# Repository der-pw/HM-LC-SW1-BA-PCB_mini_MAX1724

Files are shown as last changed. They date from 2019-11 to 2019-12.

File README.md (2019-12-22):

# AskSin++ Batterieaktor mit MAX1724 Stepup

**HM-LC-SW1-BA-PCB_mini mit einer Ausgangsspannung von 3,3V, bspw. für Mini-Lichterketten.**




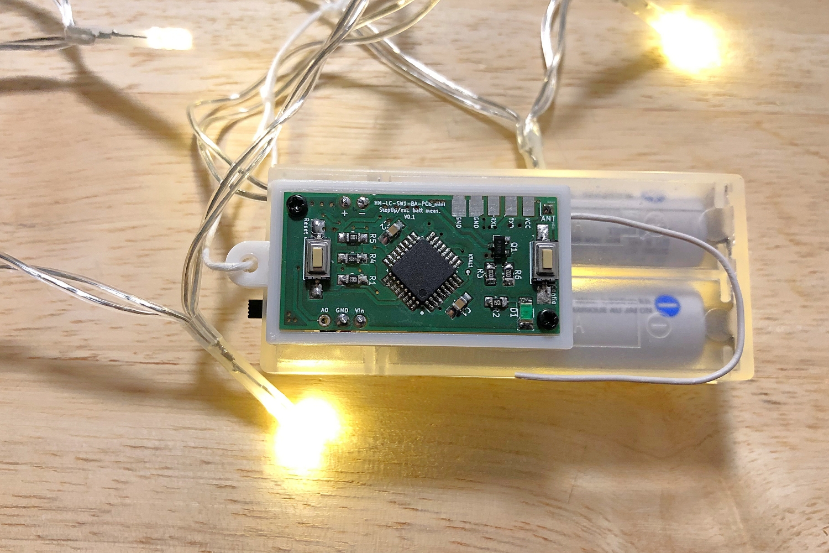
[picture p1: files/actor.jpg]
Aktor


* [Sketch](./Sketch/HM-LC-SW1-BA-PCB_extBatt.ino)
* [Gehäuse](./Case/)
* [Teileliste](./HM-LC-SW1-BA-PCB_mini_MAX1724-Parts.csv)

Der Ausgang wird über einen N-Channel MOSFET geschaltet und kann, je nach Versorgungsspannung, mit bis zu 150mA belastet werden.
Für kleine Mini-Lichterketten ist das ausreichend.
(Beispiel: eine Mini-Lichterkette aus den üblichen Grabbelschütten, mit 10 LEDs und 10Ohm Vorwiderstand benötigt ca 35mA).

**Batterie-Messung:**  
Desweiteren kann die Batteriespannung vor dem Stepup mittels Spannungsteiler gemessen werden. 
Ein angepasster Sketch liegt bei. Vielen Dank an Jérôme für die Unterstützung und das Aufzeigen, wie "einfach" doch die Batterieklasse ist. ;-)

Da in der CCU, bei diesem Aktor, die Batteriemeldung nur im Bereich von 5-15V auslöst, wird im Sketch unter ...
```
uint8_t lowbat = getList0().lowBatLimit() / 5; //factor 5 to get low bat
```
... die eingestellte Batterieschwelle durch 5 geteilt.
In der CCU müssen also die Spannungwerte mit "x5" angegeben werden.
Beispiel: Batteriemeldung bei 2,1V Versorgungsspannung. Heißt 2,1V x 5 = 10,5V. Es müssen demnach 10,5V in der CCU eingestellt werden.
Die Werte variieren je nach verwendetem Batterie.- Akkutyp und müssen "für sich selbst" gefunden werden.

## PCB

Das Platinendesign basiert auf dem [HMSensor](https://github.com/pa-pa/HMSensor/) Projekt.
Weitere Infos zur HMSensor gibt es auf [asksinpp.de](https://asksinpp.de/Projekte/psi/HMSensor/).

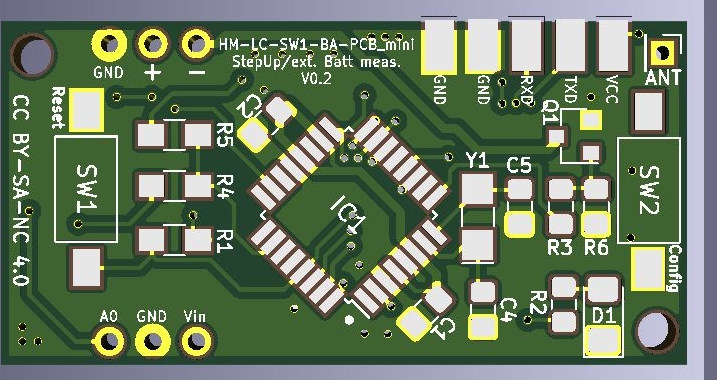
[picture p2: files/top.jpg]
PCB top

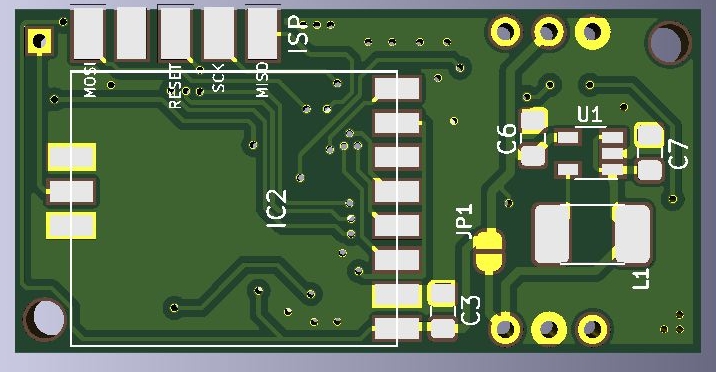
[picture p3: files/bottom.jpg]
PCB bottm


## FAQ

* `fatal error: ResetOnBoot.h: No such file or directory`  
  Es ist die aktuellste Version (ggf. master-Branch) der [AskSinPP](https://github.com/pa-pa/AskSinPP) Library zu verwenden

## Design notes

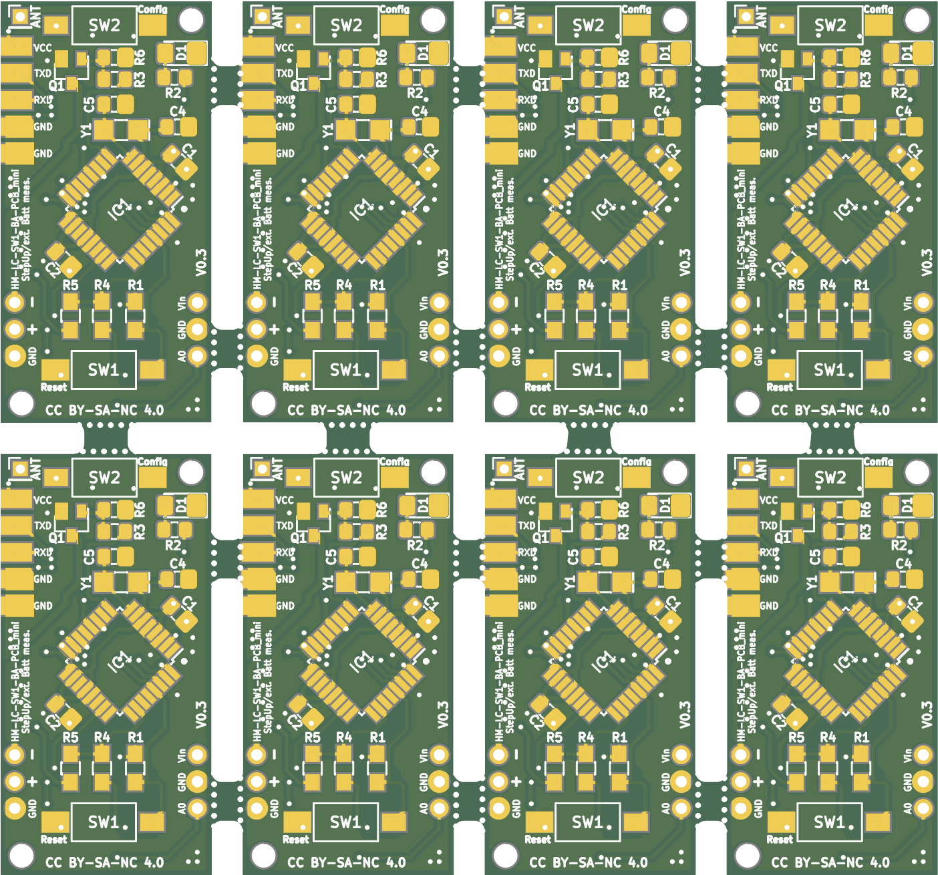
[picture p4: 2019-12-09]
Panel_2x4/unzipped/Untitled_Combined_Top.png

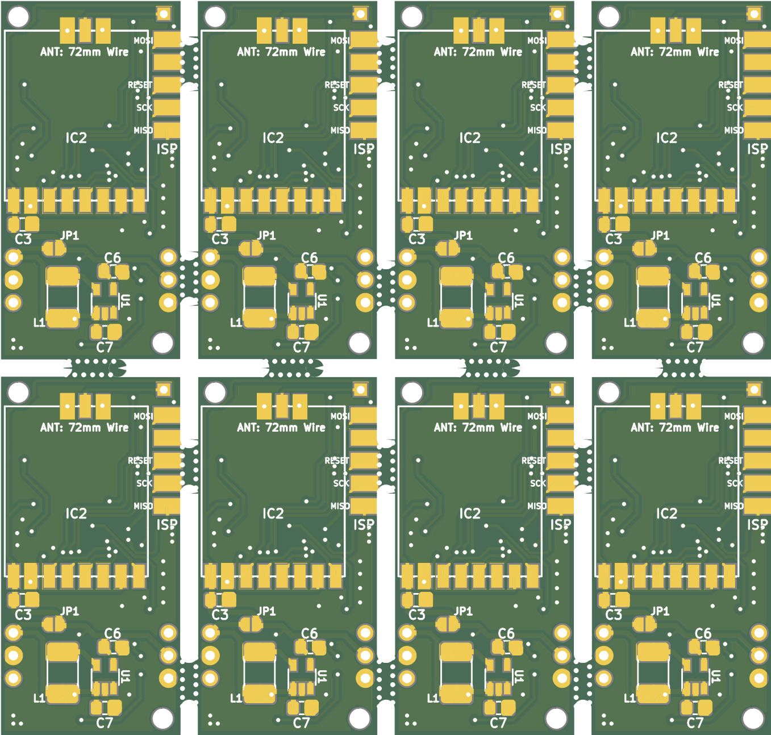
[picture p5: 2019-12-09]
Panel_2x4/Panel_2x4_Bottom.png

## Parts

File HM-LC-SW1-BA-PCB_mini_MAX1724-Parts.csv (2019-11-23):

Item | Qty | Reference(s) | Value | LibPart | Footprint | Datasheet
1 | 3 | C1, C2, C3 | 100n | Device:C | Capacitors_SMD:C_0805_HandSoldering
2 | 2 | C6, C7 | 10µ | Device:C | Capacitors_SMD:C_0805_HandSoldering
3 | 1 | D1 | LED Red | HM-LC-SW1-BA-PCB_mini_MAX1724-rescue:LED-HMSensor-StepUp-rescue-HM-LC-SW1-BA-PCB_mini2-rescue | LED_SMD:LED_1206_3216Metric_Pad1.42x1.75mm_HandSolder
4 | 1 | IC1 | ATMEGA328P-A | HM-LC-SW1-BA-PCB_mini_MAX1724-rescue:ATMEGA328P-A-HMSensor-StepUp-rescue-HM-LC-SW1-BA-PCB_mini2-rescue | Housings_QFP:TQFP-32_7x7mm_Pitch0.8mm
5 | 1 | IC2 | CC1101 | HM-LC-SW1-BA-PCB_mini_MAX1724-rescue:CC1101-HMSensor-StepUp-rescue-HM-LC-SW1-BA-PCB_mini2-rescue | Modules:CC1101_Module
6 | 1 | J1 | Conn_01x02_Female | Connector:Conn_01x02_Female | Connector_PinHeader_2.54mm:PinHeader_1x02_P2.54mm_Vertical | ~
7 | 1 | J2 | Conn_01x03_Female | Connector:Conn_01x03_Female | Connector_PinHeader_2.54mm:PinHeader_1x03_P2.54mm_Vertical | ~
8 | 1 | JP1 | Jumper_NO_Small | Device:Jumper_NO_Small | Jumper:SolderJumper-2_P1.3mm_Open_RoundedPad1.0x1.5mm
9 | 1 | L1 | 10µH | Device:L_Small | Inductor_SMD:L_1812_4532Metric_Pad1.30x3.40mm_HandSolder | https://de.aliexpress.com/item/32845690258.html
10 | 1 | P3 | ANT | HM-LC-SW1-BA-PCB_mini_MAX1724-rescue:CONN_01X01-HMSensor-StepUp-rescue-HM-LC-SW1-BA-PCB_mini2-rescue | Pin_Headers:Pin_Header_Straight_1x01_Pitch2.00mm
11 | 1 | P4 | ISP Bottom | HM-LC-SW1-BA-PCB_mini_MAX1724-rescue:CONN_01X05-HMSensor-StepUp-rescue-HM-LC-SW1-BA-PCB_mini2-rescue | Modules:Pin_Header_Straight_1x05_Pitch2.54mm_SMD_BySide
12 | 1 | P5 | ISP Top | HM-LC-SW1-BA-PCB_mini_MAX1724-rescue:CONN_01X05-HMSensor-StepUp-rescue-HM-LC-SW1-BA-PCB_mini2-rescue | Modules:Pin_Header_Straight_1x05_Pitch2.54mm_SMD_BySide
13 | 1 | Q1 | TSM2302 | Transistor_FET:IRLML2060 | Package_TO_SOT_SMD:SOT-23 | http://www.farnell.com/datasheets/1945672.pdf
14 | 1 | R1 | 10k | Device:R | Resistors_SMD:R_0805_HandSoldering
15 | 1 | R2 | 1k5 | Device:R | Resistor_SMD:R_0805_2012Metric_Pad1.15x1.40mm_HandSolder
16 | 1 | R3 | 100 | Device:R | Resistor_SMD:R_0805_2012Metric_Pad1.15x1.40mm_HandSolder
17 | 1 | R4 | 470k | Device:R | Resistors_SMD:R_0805_HandSoldering
18 | 1 | R5 | 100k | Device:R | Resistors_SMD:R_0805_HandSoldering
19 | 1 | R6 | 10k | Device:R | Resistor_SMD:R_0805_2012Metric_Pad1.15x1.40mm_HandSolder
20 | 1 | SW1 | Reset | HM-LC-SW1-BA-PCB_mini_MAX1724-rescue:SW_PUSH-HMSensor-StepUp-rescue-HM-LC-SW1-BA-PCB_mini2-rescue | Buttons_Switches_SMD:SW_SPST_FSMSM
21 | 1 | SW2 | Config | HM-LC-SW1-BA-PCB_mini_MAX1724-rescue:SW_PUSH-HMSensor-StepUp-rescue-HM-LC-SW1-BA-PCB_mini2-rescue | Buttons_Switches_SMD:SW_SPST_FSMSM
22 | 1 | U1 | MAX1724 | HM-LC-SW1-BA-PCB_mini_MAX1724-rescue:MAX1724-HM-LC-SW1-BA-PCB_mini2-rescue | Package_TO_SOT_SMD:TSOT-23-5 | https://de.aliexpress.com/item/32353066414.html

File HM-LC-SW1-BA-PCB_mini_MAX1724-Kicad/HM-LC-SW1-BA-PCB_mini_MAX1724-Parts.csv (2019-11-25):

Reference | Quantity | Value | Footprint | Datasheet
C1 C2 C3 | 3 | 100n | Capacitor_SMD:C_0805_2012Metric_Pad1.15x1.40mm_HandSolder
C4 C5 | 2 | 9p | Capacitor_SMD:C_0805_2012Metric_Pad1.15x1.40mm_HandSolder | ~
C6 C7 | 2 | 10µ | Capacitor_SMD:C_0805_2012Metric_Pad1.15x1.40mm_HandSolder
D1 | 1 | LED Red | LED_SMD:LED_1206_3216Metric_Pad1.42x1.75mm_HandSolder
IC1 | 1 | ATMEGA328P-A | Housings_QFP:TQFP-32_7x7mm_Pitch0.8mm
IC2 | 1 | CC1101 | Modules:CC1101_Module
J2 J1 | 2 | Conn_01x03_Female | Connector_PinHeader_2.54mm:PinHeader_1x03_P2.54mm_Vertical | ~
JP1 | 1 | Jumper_NO_Small | Jumper:SolderJumper-2_P1.3mm_Open_RoundedPad1.0x1.5mm
L1 | 1 | 10µH | Inductor_SMD:L_1812_4532Metric_Pad1.30x3.40mm_HandSolder | https://de.aliexpress.com/item/32845690258.html
P3 | 1 | ANT | Pin_Headers:Pin_Header_Straight_1x01_Pitch2.00mm
P4 | 1 | ISP Bottom | Modules:Pin_Header_Straight_1x05_Pitch2.54mm_SMD_BySide
P5 | 1 | ISP Top | Modules:Pin_Header_Straight_1x05_Pitch2.54mm_SMD_BySide
Q1 | 1 | TSM2302 | Package_TO_SOT_SMD:SOT-23 | http://www.farnell.com/datasheets/1945672.pdf
R1 | 1 | 10k | Resistors_SMD:R_0805_HandSoldering
R2 | 1 | 1k5 | Resistor_SMD:R_0805_2012Metric_Pad1.15x1.40mm_HandSolder
R3 | 1 | 100 | Resistor_SMD:R_0805_2012Metric_Pad1.15x1.40mm_HandSolder
R4 | 1 | 470k | Resistors_SMD:R_0805_HandSoldering
R5 | 1 | 100k | Resistors_SMD:R_0805_HandSoldering
R6 | 1 | 10k | Resistor_SMD:R_0805_2012Metric_Pad1.15x1.40mm_HandSolder
SW1 | 1 | Reset | Buttons_Switches_SMD:SW_SPST_FSMSM
SW2 | 1 | Config | Buttons_Switches_SMD:SW_SPST_FSMSM
U1 | 1 | MAX1724 | Package_TO_SOT_SMD:TSOT-23-5 | https://de.aliexpress.com/item/32353066414.html
Y1 | 1 | Crystal | Crystal:Crystal_SMD_MicroCrystal_CC7V-T1A-2Pin_3.2x1.5mm_HandSoldering | https://www.reichelt.de/uhrenquarz-keramikgeh-1-5x3-2x0-9mm-9pf-32-768-cc7v-9-p85050.html

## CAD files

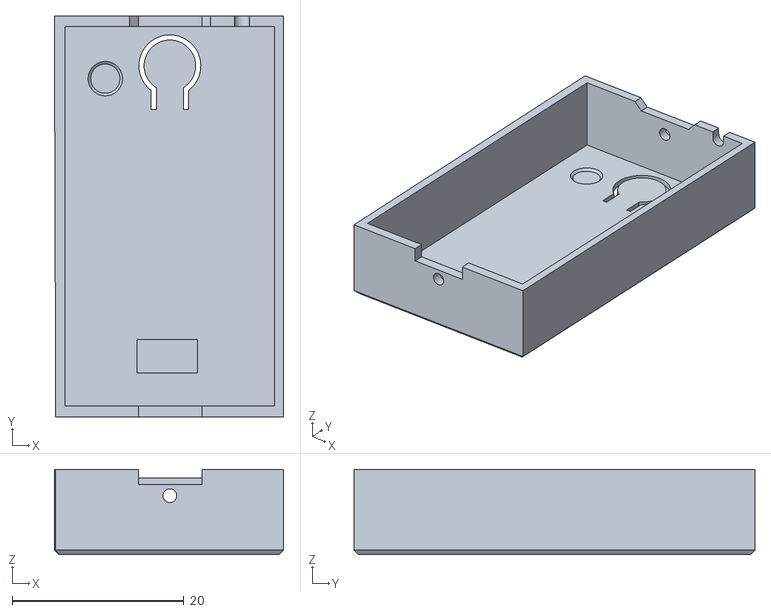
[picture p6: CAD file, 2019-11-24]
Case/Deckel.stl
26.7 x 46.7 x 9.90

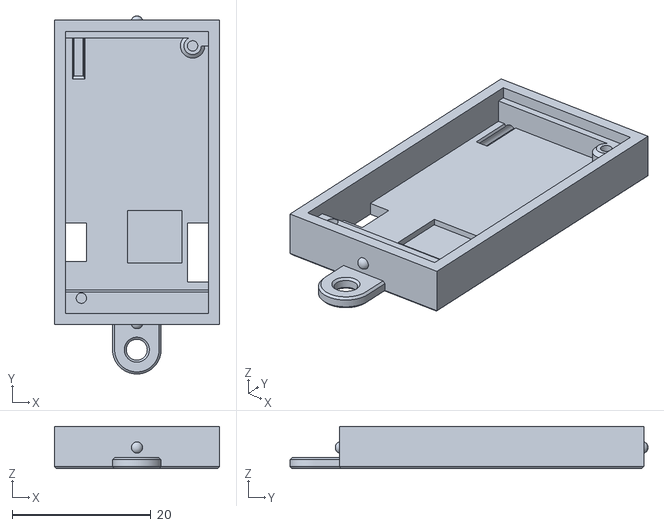
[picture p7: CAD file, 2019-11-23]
Case/Halter.stl
23.8 x 51.5 x 6.10

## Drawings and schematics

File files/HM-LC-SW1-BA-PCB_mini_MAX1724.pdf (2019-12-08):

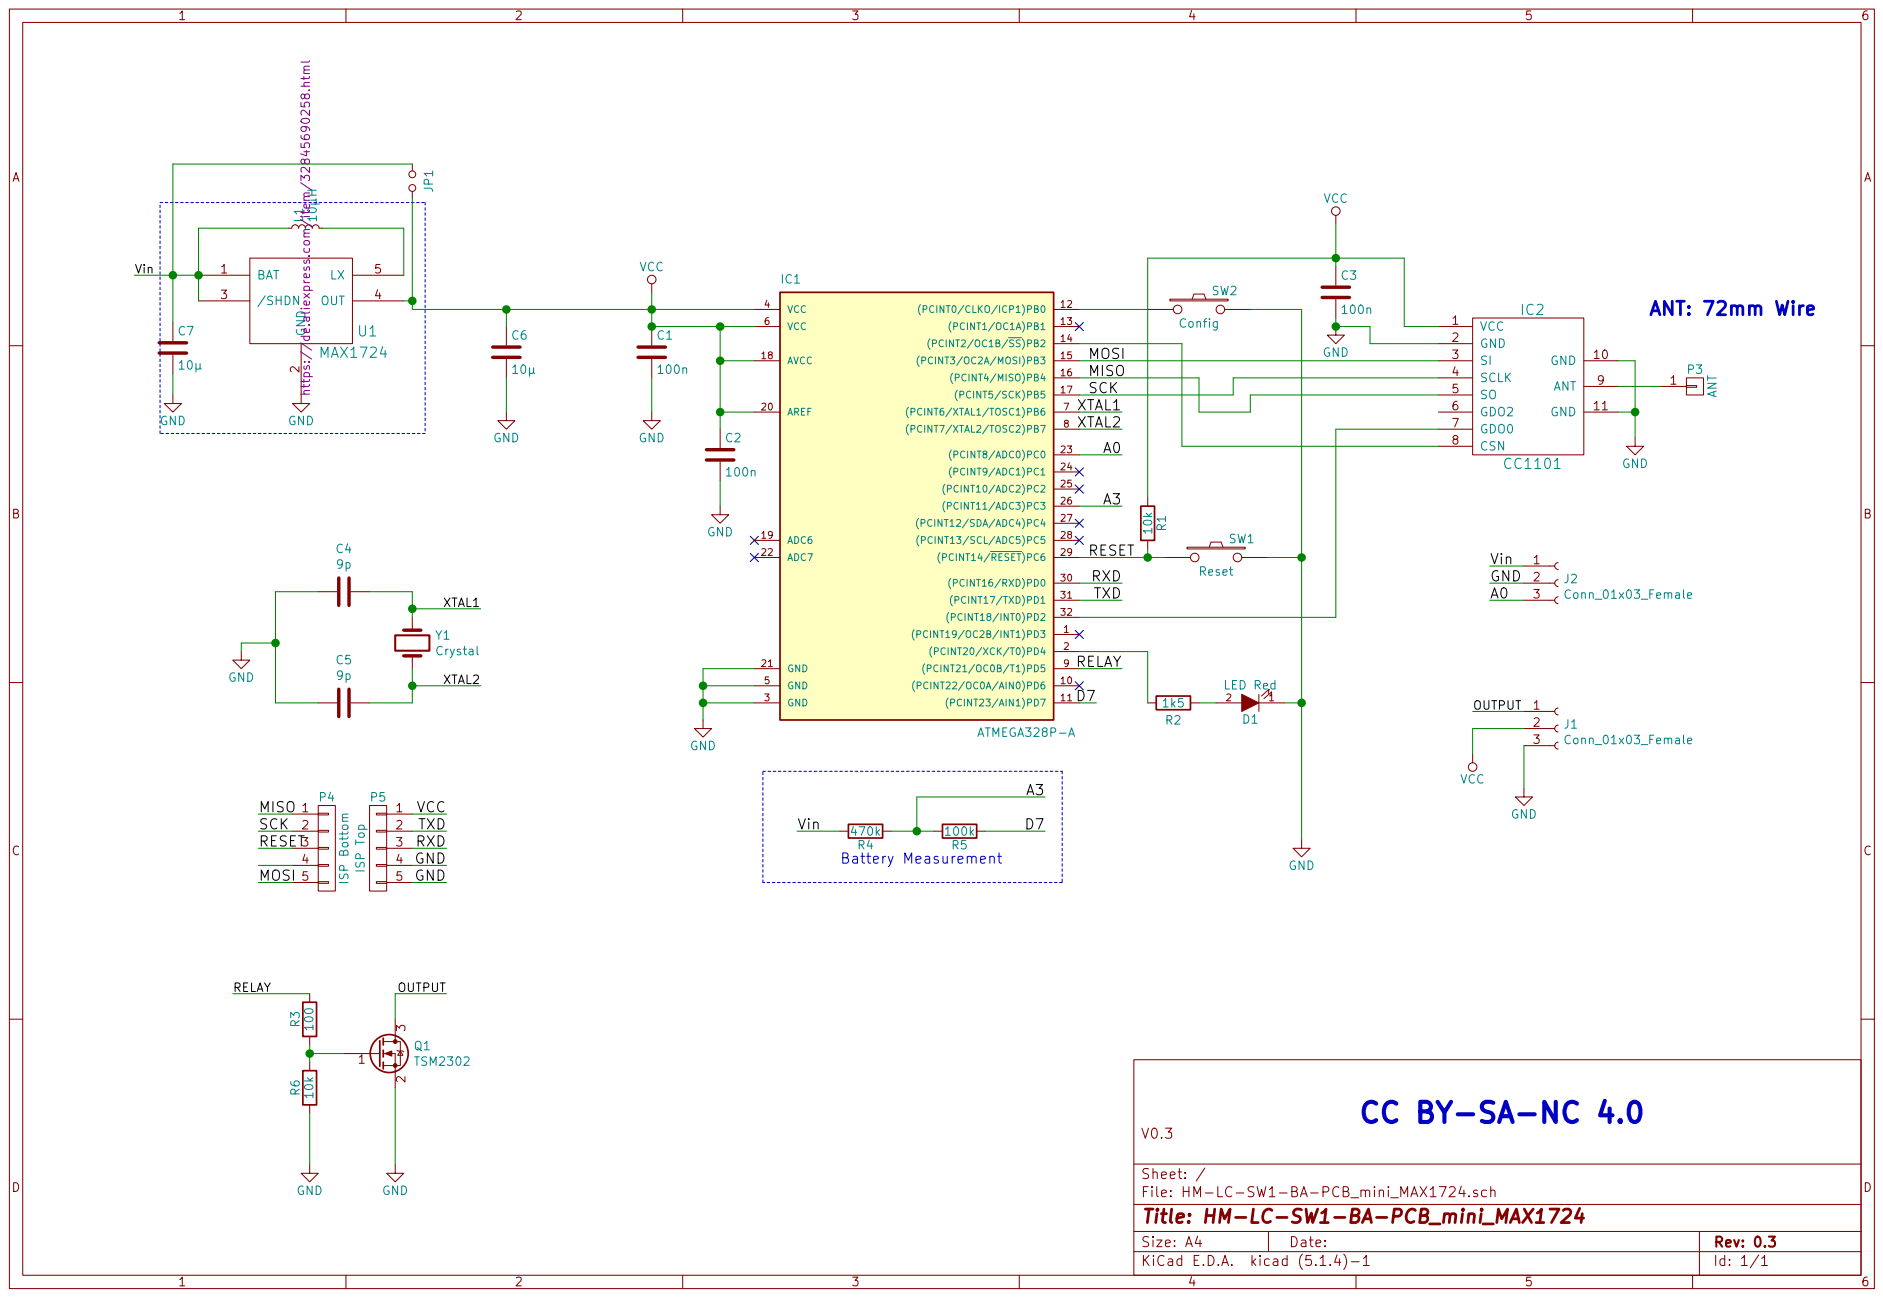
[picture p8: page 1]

2 3 Q1TSM2302 GNDL110µH https://de.aliexpress.com/item/32845690258.html JP1

MOSI
MISO
SCK

Id: 1/1 Title: HM-LC-SW1-BA-PCB_mini_MAX1724

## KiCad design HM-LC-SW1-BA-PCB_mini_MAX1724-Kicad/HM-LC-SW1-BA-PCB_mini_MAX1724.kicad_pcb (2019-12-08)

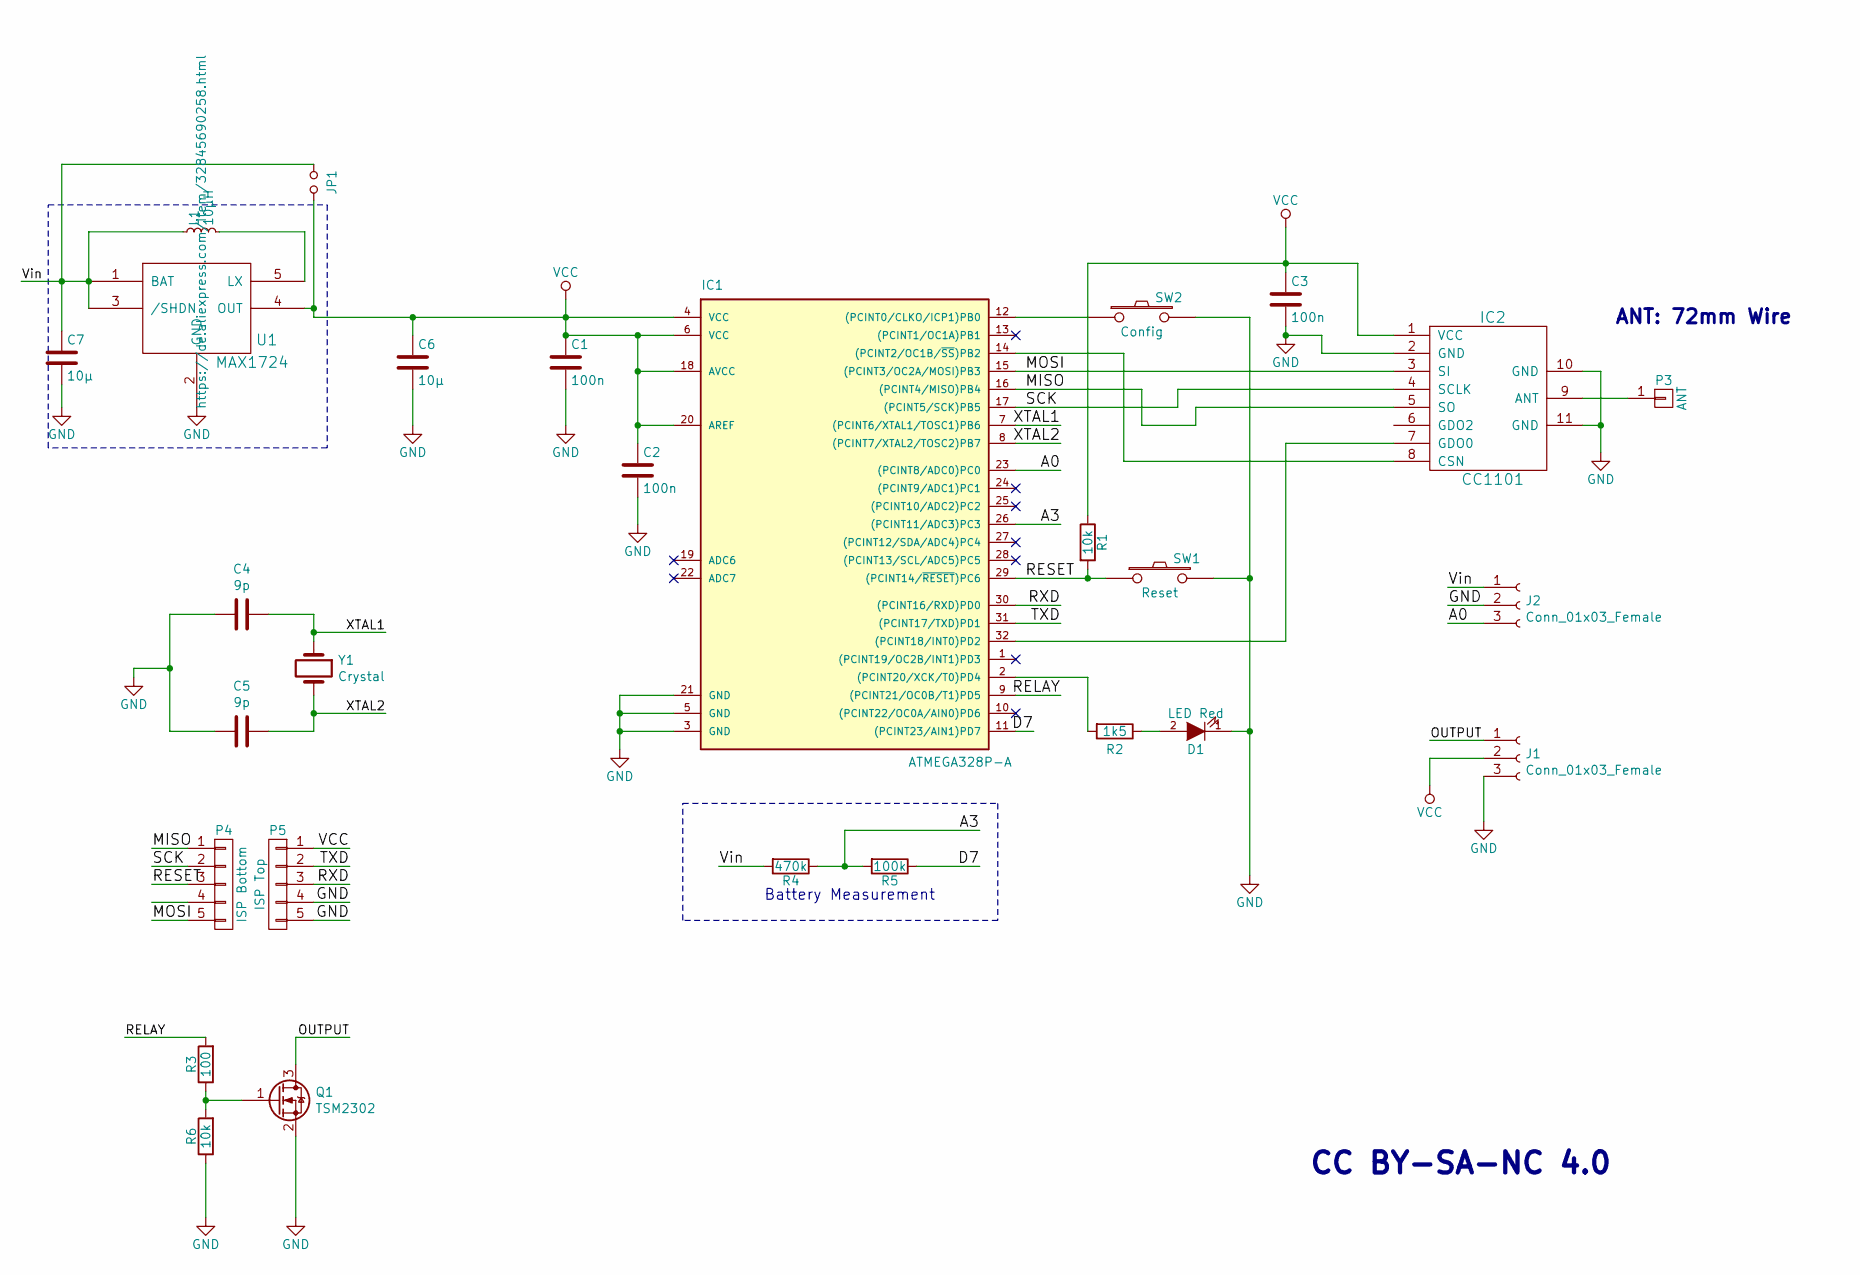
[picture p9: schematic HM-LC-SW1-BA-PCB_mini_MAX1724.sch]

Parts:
C1, C2, C3: 100n; C_0805_2012Metric_Pad1.15x1.40mm_HandSolder
C4, C5: 9p; C_0805_2012Metric_Pad1.15x1.40mm_HandSolder
C6, C7: 10µ; C_0805_2012Metric_Pad1.15x1.40mm_HandSolder
D1: LED Red; LED_1206_3216Metric_Pad1.42x1.75mm_HandSolder
IC1: ATMEGA328P-A; TQFP-32_7x7mm_Pitch0.8mm
IC2: CC1101; CC1101_Module
J1, J2: Conn_01x03_Female; PinHeader_1x03_P2.54mm_Vertical
JP1: Jumper_NO_Small; SolderJumper-2_P1.3mm_Open_RoundedPad1.0x1.5mm
L1: 10µH; L_1812_4532Metric_Pad1.30x3.40mm_HandSolder
P3: ANT; Pin_Header_Straight_1x01_Pitch2.00mm
P4: ISP Bottom; Pin_Header_Straight_1x05_Pitch2.54mm_SMD_BySide
P5: ISP Top; Pin_Header_Straight_1x05_Pitch2.54mm_SMD_BySide
Q1: TSM2302; SOT-23
R1: 10k; R_0805_HandSoldering
R2: 1k5; R_0805_2012Metric_Pad1.15x1.40mm_HandSolder
R3: 100; R_0805_2012Metric_Pad1.15x1.40mm_HandSolder
R4: 470k; R_0805_HandSoldering
R5: 100k; R_0805_HandSoldering
R6: 10k; R_0805_2012Metric_Pad1.15x1.40mm_HandSolder
SW1: Reset; SW_SPST_FSMSM
SW2: Config; SW_SPST_FSMSM
U1: MAX1724; TSOT-23-5
Y1: Crystal; Crystal_SMD_MicroCrystal_CC7V-T1A-2Pin_3.2x1.5mm_HandSolder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

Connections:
/A0: IC1.23 ((PCINT8/ADC0)PC0), J2.3
/A3: IC1.26 ((PCINT11/ADC3)PC3), R4.1, R5.2
/D7: IC1.11 ((PCINT23/AIN1)PD7), R5.1
/MISO: IC1.16 ((PCINT4/MISO)PB4), IC2.5 (SO), P4.1
/MOSI: IC1.15 ((PCINT3/OC2A/MOSI)PB3), IC2.3 (SI), P4.5
/OUTPUT: J1.1, Q1.3 (D)
/RELAY: IC1.9 ((PCINT21/OC0B/T1)PD5), R3.2
/RESET: IC1.29 ((PCINT14/~RESET~)PC6), P4.3, R1.2, SW1.1
/RXD: IC1.30 ((PCINT16/RXD)PD0), P5.3
/SCK: IC1.17 ((PCINT5/SCK)PB5), IC2.4 (SCLK), P4.2
/TXD: IC1.31 ((PCINT17/TXD)PD1), P5.2
/Vin: C7.1, J2.1, JP1.1, L1.1, R4.2, U1.1 (BAT), U1.3 (/SHDN)
/XTAL1: C4.1, IC1.7 ((PCINT6/XTAL1/TOSC1)PB6), Y1.1
/XTAL2: C5.1, IC1.8 ((PCINT7/XTAL2/TOSC2)PB7), Y1.2
GND: C1.2, C2.2, C3.2, C4.2, C5.2, C6.2, C7.2, D1.1 (K), IC1.3 (GND), IC1.5 (GND), IC1.21 (GND), IC2.2 (GND), IC2.10 (GND), IC2.11 (GND), J1.3, J2.2, P5.4, P5.5, Q1.2 (S), R6.1, SW1.2, SW2.2, U1.2 (GND)
unnamed: D1.2 (A), R2.1
unnamed: IC1.2 ((PCINT20/XCK/T0)PD4), R2.2
unnamed: IC1.12 ((PCINT0/CLKO/ICP1)PB0), SW2.1
unnamed: IC1.14 ((PCINT2/OC1B/~SS~)PB2), IC2.8 (CSN)
unnamed: IC1.32 ((PCINT18/INT0)PD2), IC2.7 (GDO0)
unnamed: IC2.9 (ANT), P3.1
unnamed: L1.2, U1.5 (LX)
unnamed: Q1.1 (G), R3.1, R6.2
VCC: C1.1, C2.1, C3.1, C6.1, IC1.4 (VCC), IC1.6 (VCC), IC1.18 (AVCC), IC1.20 (AREF), IC2.1 (VCC), J1.2, JP1.2, P5.1, R1.1, U1.4 (OUT)

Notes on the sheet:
Battery Measurement
CC BY-SA-NC 4.0
ANT: 72mm Wire

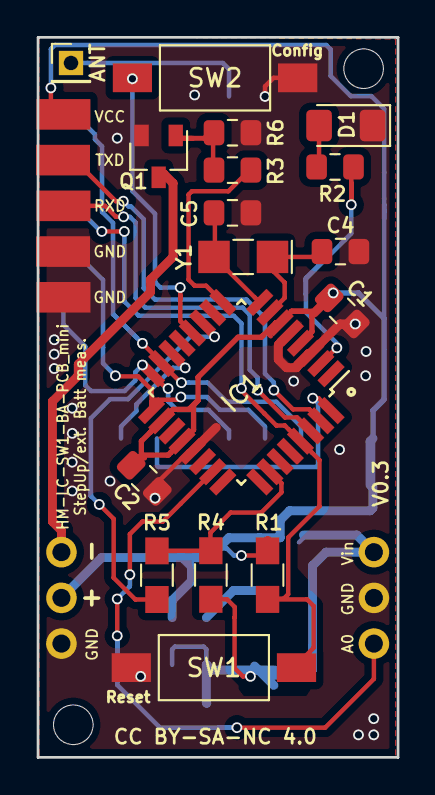
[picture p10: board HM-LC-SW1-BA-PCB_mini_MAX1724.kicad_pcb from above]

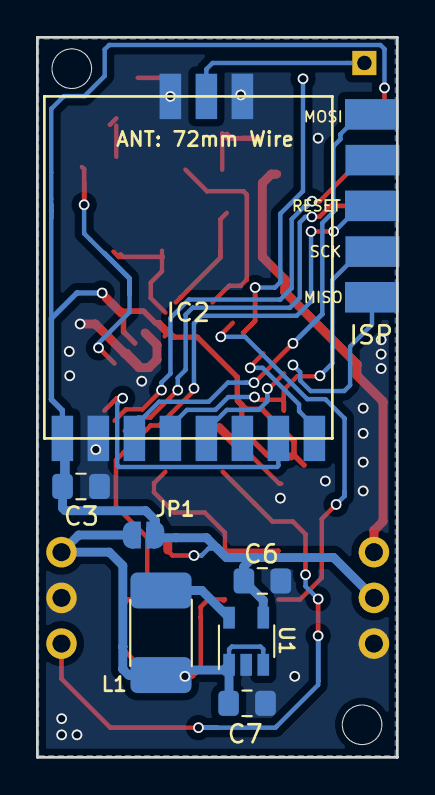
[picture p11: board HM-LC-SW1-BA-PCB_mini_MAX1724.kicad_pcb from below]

Board: 2 copper layers, 20.0 x 40.0 mm, 28 parts (8 on the bottom side), 24 nets.

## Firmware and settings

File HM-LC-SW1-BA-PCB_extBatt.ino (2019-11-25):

//- -----------------------------------------------------------------------------------------------------------------------
// AskSin++
// 2016-10-31 papa Creative Commons - http://creativecommons.org/licenses/by-nc-sa/3.0/de/
//- -----------------------------------------------------------------------------------------------------------------------

// define this to read the device id, serial and device type from bootloader section
// #define USE_OTA_BOOTLOADER

#define USE_WOR
#define EI_NOTEXTERNAL
#include <EnableInterrupt.h>
#include <AskSinPP.h>
#include <LowPower.h>

#include <Switch.h>
#include <ResetOnBoot.h>

// we use a Pro Mini
// Arduino pin for the LED
// D4 == PIN 4 on Pro Mini
#define LED_PIN 4

// Arduino pin for the config button
// B0 == PIN 8 on Pro Mini
#define CONFIG_BUTTON_PIN 8

#define RELAY1_PIN 5  //change to D5 for further PWM Options

// number of available peers per channel
#define PEERS_PER_CHANNEL 8

// all library classes are placed in the namespace 'as'
using namespace as;

// define all device properties
const struct DeviceInfo PROGMEM devinfo = {
    {0x42,0xA2,0x00},       // Device ID
    "papa42a200",           // Device Serial
    {0x00,0x6c},            // Device Model
    0x10,                   // Firmware Version
    as::DeviceType::Switch, // Device Type
    {0x01,0x00}             // Info Bytes
};

/**
 * Configure the used hardware
 */
typedef AvrSPI<10,11,12,13> RadioSPI;
//typedef AskSin<StatusLed<LED_PIN>,BattSensor<AsyncMeter<InternalVCC>>,Radio<RadioSPI,2> > Hal;
typedef AskSin<StatusLed<LED_PIN>,BattSensor<AsyncMeter<ExternalVCC<17,7,LOW,3300> >>,Radio<RadioSPI,2> > Hal;

DEFREGISTER(Reg0,DREG_INTKEY,DREG_LEDMODE,MASTERID_REGS,DREG_LOWBATLIMIT)
class SwList0 : public RegList0<Reg0> {
public:
  SwList0(uint16_t addr) : RegList0<Reg0>(addr) {}
  void defaults () {
    clear();
    lowBatLimit(22);
  }
};

// setup the device with channel type and number of channels
class SwitchType : public MultiChannelDevice<Hal,SwitchChannel<Hal,PEERS_PER_CHANNEL,SwList0>,1,SwList0> {
public:
  typedef MultiChannelDevice<Hal,SwitchChannel<Hal,PEERS_PER_CHANNEL,SwList0>,1,SwList0> DevType;
  SwitchType (const DeviceInfo& i,uint16_t addr) : DevType(i,addr) {}
  virtual ~SwitchType () {}

  virtual void configChanged () {
    DevType::configChanged();
    //uint8_t lowbat = getList0().lowBatLimit();
    uint8_t lowbat = getList0().lowBatLimit() / 5; //factor 5 to get low bat message at 1V (CCU 5V)
    DDECLN(lowbat);
    if( lowbat > 0 ) {
      battery().low(lowbat);
    }
  }
};

Hal hal;
SwitchType sdev(devinfo,0x20);
ResetOnBoot<SwitchType> resetOnBoot(sdev);
ConfigToggleButton<SwitchType> cfgBtn(sdev);
#ifndef USE_WOR
BurstDetector<Hal> bd(hal);
#endif

void initPeerings (bool first) {
  // create internal peerings - CCU2 needs this
  if( first == true ) {
    HMID devid;
    sdev.getDeviceID(devid);
    for( uint8_t i=1; i<=sdev.channels(); ++i ) {
      Peer ipeer(devid,i);
      sdev.channel(i).peer(ipeer);
    }
  }
}

void setup () {
  DINIT(57600,ASKSIN_PLUS_PLUS_IDENTIFIER);
  bool first = sdev.init(hal);
  sdev.channel(1).init(RELAY1_PIN);
  buttonISR(cfgBtn,CONFIG_BUTTON_PIN);
  initPeerings(first);
#ifndef USE_WOR
  // start burst detection
  bd.enable(sysclock);
#endif
  // stay on for 15 seconds after start
  hal.activity.stayAwake(seconds2ticks(15));
  // measure battery every hour
  hal.battery.init(seconds2ticks(60UL*60),sysclock);
  resetOnBoot.init();
  
  sdev.initDone();
  //if (sdev.getMasterID() == HMID::broadcast) { DPRINTLN(F("START PAIRING")); sdev.startPairing(); } // start pairing of no master id is present
}

void loop() {
  bool worked = hal.runready();
  bool poll = sdev.pollRadio();
  if( worked == false && poll == false ) {
    hal.activity.savePower<Sleep<> >(hal);
  }
}

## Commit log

2019-11-23 gerber upload
    [HM-LC-SW1-BA-PCB_mini_MAX1724-B_Cu.gbl, HM-LC-SW1-BA-PCB_mini_MAX1724-B_Mask.gbs, HM-LC-SW1-BA-PCB_mini_MAX1724-B_SilkS.gbo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]
2019-11-23 order structure
    [HM-LC-SW1-BA-PCB_mini_MAX1724.kicad_pcb, HM-LC-SW1-BA-PCB_mini_MAX1724.sch]
2019-11-23 upload parts table
    [HM-LC-SW1-BA-PCB_mini_MAX1724-Parts.csv]
2019-11-24 change footprint for L1
    [HM-LC-SW1-BA-PCB_mini_MAX1724-B_Cu.gbl, HM-LC-SW1-BA-PCB_mini_MAX1724-B_Mask.gbs, HM-LC-SW1-BA-PCB_mini_MAX1724-B_SilkS.gbo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]
2019-11-25 update to V0.2
    [HM-LC-SW1-BA-PCB_mini_MAX1724-B_Cu.gbl, HM-LC-SW1-BA-PCB_mini_MAX1724-B_Mask.gbs, HM-LC-SW1-BA-PCB_mini_MAX1724-B_SilkS.gbo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]
2019-11-25 change Relay to D5
    for further PWM options
2019-11-25 update pcb pics
2019-11-25 add V0.2 Panel
    [combined.GKO, combined.drl, combined.gbl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]
2019-12-05 update to V0.3
    improvement GND area inductor
    [HM-LC-SW1-BA-PCB_mini_MAX1724-B_Cu.gbl, HM-LC-SW1-BA-PCB_mini_MAX1724-B_Mask.gbs, HM-LC-SW1-BA-PCB_mini_MAX1724-B_SilkS.gbo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]
2019-12-05 V0.3
    some small fixes
    [HM-LC-SW1-BA-PCB_mini_MAX1724-B_Cu.gbl, HM-LC-SW1-BA-PCB_mini_MAX1724-B_Mask.gbs, HM-LC-SW1-BA-PCB_mini_MAX1724-B_SilkS.gbo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]
2019-12-08 update panel to v0.3
    [combined.GKO, combined.drl, combined.gbl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]
2019-12-09 panelize
    try an older Version of pcb panilzer
    [combined.GKO, combined.drl, combined.gbl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]

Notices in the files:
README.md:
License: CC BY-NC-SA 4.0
